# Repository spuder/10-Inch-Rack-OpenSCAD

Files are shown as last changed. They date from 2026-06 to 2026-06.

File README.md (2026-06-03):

# 10 Inch Rack Generator

OpenSCAD file to generate a 10 inch rack for 3d printing

[https://makerworld.com/models/1765102](https://makerworld.com/en/models/1765102-10-inch-mini-rack-generator)

10 Inch Mini-Rack v4

## My Presets

My personal model configurations are saved as Customizer presets in
[`10InchRackGenerator.json`](10InchRackGenerator.json). OpenSCAD auto-loads this
file (it shares the `.scad` basename), so each saved model appears in the
Customizer's preset dropdown — pick one, Render (f6), then export the STL.

To build a preset from the command line:

```bash
openscad -p 10InchRackGenerator.json -P "Xyber Hydra" -o out.stl 10InchRackGenerator.scad
```

Every saved preset is also covered by the test suite (see the
`customizer presets render` case below), so presets added via the Customizer get
rendered automatically with no test edits.

## Testing

### Manual Testing
1. Open OpenScad
2. Modify variables
3. Click 'Render' button (f6)

### CLI Testing
1. `openscad -o foobar.stl 10InchRackGenerator.scad`

### Automated Tests

Requires [bats-core](https://github.com/bats-core/bats-core), `openscad`, and
`jq` (used to read presets) on your `PATH`.

```bash
# Fast preview tests — renders PNG images, ~1s per case
make test

# Full geometry validation — renders STL files via CGAL, ~35s per case
make test-stl

# Run a single test by name
make test TEST=missing_air_holes

# Run a single test with stl
RENDER_STL=1 make test TEST=missing_air_holes

# Render every model saved in 10InchRackGenerator.json
make test TEST="customizer presets render"
```

The `customizer presets render` case reads
[`10InchRackGenerator.json`](10InchRackGenerator.json) at runtime, so any model
you save from the GUI Customizer is tested automatically — no test edits needed.

Output files land in `tests/renders/`. Each test case produces up to five PNG previews:

```
tests/renders/
  default_corner.png
  default_front.png
  default_side.png
  default_top.png
  default_bottom.png
  default.stl          ← only present after make test-stl
```

To run a specific named case and also get its STL alongside the PNGs:

```bash
make test TEST=dell_optiplex_7020
# → tests/renders/dell_optiplex_7020_{corner,front,side,top,bottom}.png
# → tests/renders/dell_optiplex_7020.stl
```

## Keystones

An openscad file to generate keystones is avilable [on makerworld](https://makerworld.com/en/models/2882057-keystone-jack#profileId-3219015)
A stl is available at ./keystone.stl and ./keystone.3mf

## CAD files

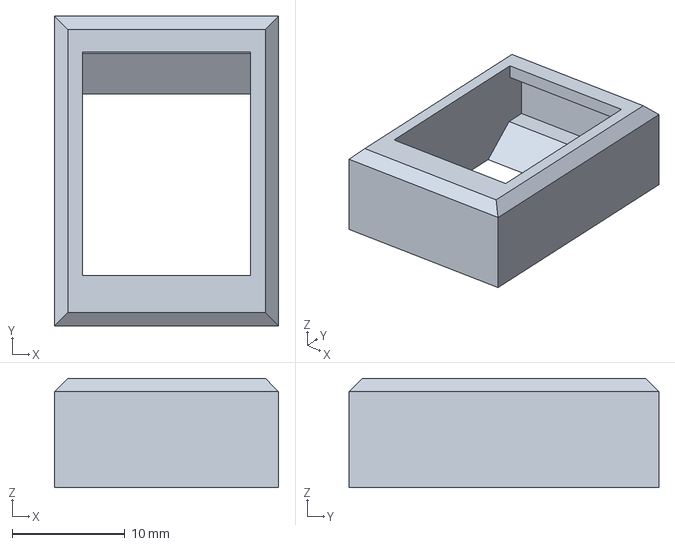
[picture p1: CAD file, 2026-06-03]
keystone.3mf
19.9 x 27.5 x 9.70 mm

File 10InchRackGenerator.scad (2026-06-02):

rack_width = 254.0; // [ 254.0:10 inch, 152.4:6 inch]
// Height of the rack in U units, can be a fraction for partial U (e.g. 1.5 for 1U plus half of the next U)
rack_height = 1.0; // [0.5:0.5:5]


component_width = 110.0;
component_depth = 122.0;
component_height = 28.30;

// ========================================
/* [Keystones] */
// Add keystone jacks to the front panel
keystones = false; // [true: Place keystone jacks, false: Remove keystone jacks]

// ========================================
/* [Holes] */
// Adds small cutout a USB or Power cable could be routed through to the front
front_wire_holes = false; // [true:Show front wire holes, false:Hide front wire holes]
// Diameter of wire to route through front_wire_holes.
wire_diameter = 7; // Diameter of power wire holes
// Adds hexagon air cutouts to reduce material and improve cooling.
air_holes = true; // [true:Show air holes, false:Hide air holes]

// ========================================
/* [Advanced] */
// Used when rack_height is a fraction, cuts a half oval for screws, otherwise will cover up the hole
half_height_holes = true; // [true:Show partial holes at edges, false:Hide partial holes]
// Thickness of the shell that wraps around the part.
case_thickness = 6; // Thickness of case walls
// Thickness of the front panel (the flat face plate).
front_plate_thickness = 3.0;
// Make the front plate solid (no hole), useful to hide a part not needing to be accessed from the exterior.
front_plate_hole = true; // [true:Show front plate hole, false:Solid front plate]
// Prevent part from sliding out the front by adding a small 0.6mm lip around the front plate hole.
front_lip = true; // [true:Show front lip, false:Hide front lip]
// Default gap between part and print walls
tolerance = 0.42;

// ========================================
/* [Hidden] */
height = 44.45 * rack_height;


// The main module containing all internal variables
module switch_mount(switch_width, switch_height, switch_depth) {
    //6 inch racks (mounts=152.4mm; rails=15.875mm; usable space=120.65mm)
    //10 inch racks (mounts=254.0mm; rails=15.875mm; usable space=221.5mm)
    chassis_width = min(switch_width + (2 * case_thickness), (rack_width == 152.4) ? 120.65 : 221.5);
    corner_radius = 4.0;
    chassis_edge_radius = 2.0;
    tolerance = 0.42;

    zip_tie_hole_count = 8;
    zip_tie_hole_width = 1.5;
    zip_tie_hole_length = 5;
    zip_tie_indent_depth = 2;
    zip_tie_cutout_depth = 7;

    // When the front is solid the switch slides in from the back, so everything
    // shifts rearward by front_plate_thickness to keep zip ties at the switch's back face.
    solid_z_offset = front_plate_hole ? 0 : front_plate_thickness;
    chassis_depth_main = switch_depth + zip_tie_cutout_depth + solid_z_offset;
    chassis_depth_indented = chassis_depth_main - zip_tie_indent_depth;

    hole_total_width = zip_tie_hole_count * zip_tie_hole_width;
    space_between_holes = (rack_width - hole_total_width) / (zip_tie_hole_count + 1);

    $fn = 64;

    // Calculated dimensions
    cutout_w = switch_width + (2 * tolerance);
    cutout_h = switch_height + (2 * tolerance);
    cutout_x = (rack_width - cutout_w) / 2;
    cutout_y = (height - cutout_h) / 2;

    // Keystone placement — jack X span (width) goes horizontal, jack Z span (height) goes vertical
    keystone_outer_width  = 19.9; // jack_width + wall = (front_hole_width + wall) + wall
    keystone_outer_height = 27.5; // jack_height + wall
    // Left edge of left keystone pinned to 210/2 from centreline → 210mm outer-to-outer for the mirrored pair
    keystone_tx = rack_width/2 - 105;
    keystone_ty = (height - keystone_outer_height) / 2;

    // Helper modules
    module capsule_slot_2d(L, H) {
        hull() {
            translate([-L/2 + H/2, 0]) circle(r=H/2);
            translate([L/2 - H/2, 0]) circle(r=H/2);
        }
    }
    
    module rounded_rect_2d(w, h, r) {
        hull() {
            translate([r, r]) circle(r=r);
            translate([w-r, r]) circle(r=r);
            translate([w-r, h-r]) circle(r=r);
            translate([r, h-r]) circle(r=r);
        }
    }

    module rounded_chassis_profile(width, height, radius, depth) {
        hull() {
            translate([radius, radius, 0]) cylinder(h = depth, r = radius);
            translate([width - radius, radius, 0]) cylinder(h = depth, r = radius);
            translate([radius, height - radius, 0]) cylinder(h = depth, r = radius);
            translate([width - radius, height - radius, 0]) cylinder(h = depth, r = radius);
        }
    }
    
    // Create the main body as a separate module
    module main_body() {
        side_margin = (rack_width - chassis_width) / 2;
        chassis_height = min(switch_height + (2 * case_thickness), height);
        union() {
            // Front panel
            linear_extrude(height = front_plate_thickness) {
                rounded_rect_2d(rack_width, height, corner_radius);
            }
            // Chassis body
            translate([side_margin, (height - chassis_height) / 2, front_plate_thickness]) {
                rounded_chassis_profile(chassis_width, chassis_height, chassis_edge_radius, chassis_depth_main - front_plate_thickness);
            }
        }
    }
    
    // Create switch cutout with optional lip
    module switch_cutout() {
        if (front_plate_hole && front_lip) {
            lip_thickness = 1.2;
            lip_depth = 0.60;
            // Main cutout minus lip (centered)
            translate([
                (rack_width - (cutout_w - 2*lip_thickness)) / 2,
                (height - (cutout_h - 2*lip_thickness)) / 2,
                -tolerance
            ]) {
                cube([cutout_w - 2*lip_thickness, cutout_h - 2*lip_thickness, chassis_depth_main]);
            }
            // Switch cutout above the lip (centered)
            translate([
                (rack_width - cutout_w) / 2,
                (height - cutout_h) / 2,
                lip_depth
            ]) {
                cube([cutout_w, cutout_h, chassis_depth_main]);
            }
        } else {
            // Full cutout: starts at front face when front_plate_hole, or behind front panel when solid
            z_start = front_plate_hole ? -tolerance : front_plate_thickness;
            z_depth = front_plate_hole ? chassis_depth_main + 2*tolerance : chassis_depth_main - front_plate_thickness + tolerance;
            translate([
                (rack_width - cutout_w) / 2,
                (height - cutout_h) / 2,
                z_start
            ]) {
                cube([cutout_w, cutout_h, z_depth]);
            }
        }
    }
    
    // Create all rack holes
    module all_rack_holes() {
        // Rack standard: 3 holes per U, with specific positioning
        // Each U is 44.45mm, holes are at specific positions within each U
        hole_spacing_x = (rack_width == 152.4) ? 136.526 : 236.525; // 6 inch : 10 inch rack
        hole_left_x = (rack_width - hole_spacing_x) / 2;
        hole_right_x = (rack_width + hole_spacing_x) / 2;

        // 10 inch rack = 10x7mm oval
        // 6 inch rack = 3.25 x 6.5mm oval
        slot_len = (rack_width == 152.4) ? 6.5 : 10.0;
        slot_height = (rack_width == 152.4) ? 3.25 : 7.0;

        // Standard rack hole positions within each 1U (44.45mm) unit:
        // First hole: 6.35mm from top of U
        // Second hole: 22.225mm from top of U (middle)
        // Third hole: 38.1mm from top of U (6.35mm from bottom)
        u_hole_positions = [6.35, 22.225, 38.1]; // positions within each U
        
        // Calculate how many full and partial U units we need to consider
        max_u = ceil(rack_height); // Include partial U units
        
        for (side_x = [hole_left_x, hole_right_x]) {
            for (u = [0:max_u-1]) {
                for (hole_pos = u_hole_positions) {
                    // Calculate hole position from top of entire rack
                    hole_y = height - (u * 44.45 + hole_pos);
                    // Always show holes that are at least partially within the rack height
                    // Always show holes fully inside the rack
                    fully_inside = (hole_y >= slot_height/2 && hole_y <= height - slot_height/2);
                    // Show partial holes at edge only if half_height_holes is true
                    partially_inside = (hole_y + slot_height/2 > 0 && hole_y - slot_height/2 < height);
                    show_hole = fully_inside || (half_height_holes && partially_inside && !fully_inside);
                    if (show_hole) {
                        translate([side_x, hole_y, 0]) {
                            linear_extrude(height = chassis_depth_main) {
                                capsule_slot_2d(slot_len, slot_height);
                            }
                        }
                    }
                }
            }
        }
    }
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

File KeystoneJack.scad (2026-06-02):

cross_section_preview=true;
module keystone(
){
    e=0.01; // epsilon for coplanar face fixes, fixes bug where some faces leave a thin sliver of material
    wall=2.5;
    front_hole_width=14.9;
    front_hole_height=16.3;
    front_hole_z_offset=4.28;
    front_hole_lip=0;

    jack_width=front_hole_width+wall;
    jack_height=25;
    jack_depth=9.7;
    front_large_catch_depth=3;
    front_chamfer_angle=50; // degrees from horizontal (depth axis)

    back_hole_height=24.4;
    back_hole_z_offset=1.9;

    back_small_catch_length=2;
    back_small_catch_depth=1.4;

    back_large_catch_length=2.6;
    back_large_catch_depth=1.3;
    
    back_chamfer=1.2;

    // Flip entire part because I accidentially desinged it upside down
    translate([0, 0, jack_height + wall]) 
    mirror([0, 0, 1]) {
        union(){
            difference(){
                // Make solid cube
                cube([jack_width+wall,jack_depth,jack_height+wall]);
            // Cut out the front hole
            translate([(jack_width+wall-front_hole_width)/2,0,front_hole_z_offset])
                color("blue")
                cube([front_hole_width,jack_depth+wall,front_hole_height]);
            // Cut out the back hole. It should be extruded to front_large_catch_depth
            translate([(jack_width+wall-front_hole_width)/2,front_large_catch_depth,back_hole_z_offset])
                color("red")
                cube([front_hole_width,jack_depth+wall-front_large_catch_depth,back_hole_height]);

            // Cut out chamfer on front face of small catch
            color("green")
            translate([wall + front_hole_width, 0, 0])
                rotate([0, -90, 0])
                    linear_extrude(front_hole_width)
                        polygon([
                            [front_hole_z_offset + front_hole_height - e, front_hole_lip - e],          // A: shifted e below catch floor to avoid coplanar artifact
                            [front_hole_z_offset + front_hole_height + (front_large_catch_depth - front_hole_lip) * tan(front_chamfer_angle), front_large_catch_depth],  // B: angle-derived point
                            [front_hole_z_offset + front_hole_height - e, front_large_catch_depth]      // C: inner corner, same e shift as A
                        ]);

            // Cut out chamefer on front face of large catch
            // color("orange")
            // translate([wall + front_hole_width, 0, 0])
            //     rotate([0, -90, 0])
            //         linear_extrude(front_hole_width)
            //             polygon([
            //                 [front_hole_z_offset+e, front_hole_lip],  // A: front face, bottom of front hole
            //                 [back_hole_z_offset,  front_large_catch_depth],     // B: inner ledge, bottom of back hole
            //                 [front_hole_z_offset, front_large_catch_depth]      // C: inner ledge, same Z as A
            //             ]);

            // Front directional triangle emboss (cut into face)
            color("yellow")
                translate([(jack_width+wall)/2, 0.4, (front_hole_z_offset + front_hole_height + jack_height + wall) / 2])
                    rotate([90, 0, 0])
                        linear_extrude(height = 0.4+e)
                            polygon([
                                [0, -2],
                                [-2, 2],
                                [2, 2]
                            ]);

            // Chamfer back bottom edge (along X)
            translate([jack_width+wall+e, 0, -e])
                rotate([0, -90, 0])
                    linear_extrude(jack_width+wall+2*e)
                        polygon([[-e, jack_depth+e], [back_chamfer, jack_depth+e], [-e, jack_depth-back_chamfer]]);

            // Chamfer back top edge (along X)
            translate([jack_width+wall+e, 0, -e])
                rotate([0, -90, 0])
                    linear_extrude(jack_width+wall+2*e)
                        polygon([[jack_height+wall+2*e, jack_depth+e], [jack_height+wall+2*e-back_chamfer, jack_depth+e], [jack_height+wall+2*e, jack_depth-back_chamfer]]);

            // Chamfer back left edge (along Z)
            translate([0, 0, -e])
                linear_extrude(jack_height+wall+2*e)
                    polygon([[-e, jack_depth+e], [back_chamfer, jack_depth+e], [-e, jack_depth-back_chamfer]]);

            // Chamfer back right edge (along Z)
            translate([0, 0, -e])
                linear_extrude(jack_height+wall+2*e)
                    polygon([[jack_width+wall+e, jack_depth+e], [jack_width+wall+e-back_chamfer, jack_depth+e], [jack_width+wall+e, jack_depth-back_chamfer]]);

            } // end difference

            // Small back catch (added geometry)
            color("purple")
                translate([wall + front_hole_width, 0, 0])
                    rotate([0, -90, 0])
                        linear_extrude(front_hole_width)
                            polygon([
                                [back_hole_z_offset + back_hole_height - back_small_catch_length, jack_depth - back_small_catch_depth],  // A
                                [back_hole_z_offset + back_hole_height,                           jack_depth - back_small_catch_depth],  // B
                                [back_hole_z_offset + back_hole_height,                           jack_depth],                           // C
                                [back_hole_z_offset + back_hole_height - back_small_catch_length, jack_depth]                            // D
                            ]);

            // Large back catch (added geometry)
            color("cyan")
                translate([wall + front_hole_width, 0, 0])
                    rotate([0, -90, 0])
                        linear_extrude(front_hole_width)
                            polygon([
                                [back_hole_z_offset,                           jack_depth - back_large_catch_depth],  // A
                                [back_hole_z_offset + back_large_catch_length, jack_depth - back_large_catch_depth],  // B
                                [back_hole_z_offset + back_large_catch_length, jack_depth],                           // C
                                [back_hole_z_offset,                           jack_depth]                            // D
                            ]);

        } // end union
    }
}


if ($preview && cross_section_preview) {
    intersection() {
        keystone();
        cube([10, 35, 50]);
    }
} else if ($preview) {
    keystone();
} else {
    rotate([90, 0, 0])
        keystone();
}

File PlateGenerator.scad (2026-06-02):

// Rack Width 10 inch or 6 inch
rack_width = 254.0; // [ 254.0:10 inch, 152.4:6 inch]
// Height (measured in U)
rack_height = 1.0; // [0.5:0.5:5]
// Thickness of the front plate
front_thickness = 3.0;
// Radius for rounded corners on the front plate
corner_radius = 4.0;
half_height_holes = true; // [true:Show partial holes at edges, false:Hide partial holes]
//Adds additional strength
ribs = true; // [true:Show structural ribs, false:Hide structural ribs]
//Optional keystone jacks
keystones = 0; // [0:1:10]

/* [Hidden] */
height = 44.45 * rack_height;

tolerance = 0.42;

// Structural rib parameters
rib_thickness = 2.0;
rib_depth = 3.0;
rib_spacing = 15.0; // Distance between ribs
chamfer_size = 0.5; // Size of chamfer on rib edges

module keystone() {
    e=0.01;
    wall=2.5;
    front_hole_width=14.9;
    front_hole_height=16.3;
    front_hole_z_offset=4.28;
    front_hole_lip=0;

    jack_width=front_hole_width+wall;
    jack_height=25;
    jack_depth=9.7;
    front_large_catch_depth=3;
    front_chamfer_angle=50;

    back_hole_height=24.4;
    back_hole_z_offset=1.9;

    back_small_catch_length=2;
    back_small_catch_depth=1.4;

    back_large_catch_length=2.6;
    back_large_catch_depth=1.3;

    back_chamfer=1.2;

    translate([0, 0, jack_height + wall])
    mirror([0, 0, 1]) {
        union(){
            difference(){
                cube([jack_width+wall,jack_depth,jack_height+wall]);
                translate([(jack_width+wall-front_hole_width)/2,0,front_hole_z_offset])
                    cube([front_hole_width,jack_depth+wall,front_hole_height]);
                translate([(jack_width+wall-front_hole_width)/2,front_large_catch_depth,back_hole_z_offset])
                    cube([front_hole_width,jack_depth+wall-front_large_catch_depth,back_hole_height]);
                translate([wall + front_hole_width, 0, 0])
                    rotate([0, -90, 0])
                        linear_extrude(front_hole_width)
                            polygon([
                                [front_hole_z_offset + front_hole_height - e, front_hole_lip - e],
                                [front_hole_z_offset + front_hole_height + (front_large_catch_depth - front_hole_lip) * tan(front_chamfer_angle), front_large_catch_depth],
                                [front_hole_z_offset + front_hole_height - e, front_large_catch_depth]
                            ]);
                translate([jack_width+wall+e, 0, -e])
                    rotate([0, -90, 0])
                        linear_extrude(jack_width+wall+2*e)
                            polygon([[-e, jack_depth+e], [back_chamfer, jack_depth+e], [-e, jack_depth-back_chamfer]]);
                translate([jack_width+wall+e, 0, -e])
                    rotate([0, -90, 0])
                        linear_extrude(jack_width+wall+2*e)
                            polygon([[jack_height+wall+2*e, jack_depth+e], [jack_height+wall+2*e-back_chamfer, jack_depth+e], [jack_height+wall+2*e, jack_depth-back_chamfer]]);
                translate([0, 0, -e])
                    linear_extrude(jack_height+wall+2*e)
                        polygon([[-e, jack_depth+e], [back_chamfer, jack_depth+e], [-e, jack_depth-back_chamfer]]);
                translate([0, 0, -e])
                    linear_extrude(jack_height+wall+2*e)
                        polygon([[jack_width+wall+e, jack_depth+e], [jack_width+wall+e-back_chamfer, jack_depth+e], [jack_width+wall+e, jack_depth-back_chamfer]]);
                translate([(jack_width+wall)/2, 0.4, (front_hole_z_offset + front_hole_height + jack_height + wall) / 2])
                    rotate([90, 0, 0])
                        linear_extrude(height = 0.4+e)
                            polygon([[0, -2], [-2, 2], [2, 2]]);
            }
            translate([wall + front_hole_width, 0, 0])
                rotate([0, -90, 0])
                    linear_extrude(front_hole_width)
                        polygon([
                            [back_hole_z_offset + back_hole_height - back_small_catch_length, jack_depth - back_small_catch_depth],
                            [back_hole_z_offset + back_hole_height,                           jack_depth - back_small_catch_depth],
                            [back_hole_z_offset + back_hole_height,                           jack_depth],
                            [back_hole_z_offset + back_hole_height - back_small_catch_length, jack_depth]
                        ]);
            translate([wall + front_hole_width, 0, 0])
                rotate([0, -90, 0])
                    linear_extrude(front_hole_width)
                        polygon([
                            [back_hole_z_offset,                           jack_depth - back_large_catch_depth],
                            [back_hole_z_offset + back_large_catch_length, jack_depth - back_large_catch_depth],
                            [back_hole_z_offset + back_large_catch_length, jack_depth],
                            [back_hole_z_offset,                           jack_depth]
                        ]);
        }
    }
}

// The main module for the plate generator
module plate_generator() {
    $fn = 64;

    // Helper module for capsule-shaped slots (oval holes)
    module capsule_slot_2d(L, H) {
        hull() {
            translate([-L/2 + H/2, 0]) circle(r=H/2);
            translate([L/2 - H/2, 0]) circle(r=H/2);
        }
    }
    
    // Helper module for rounded rectangle
    module rounded_rect_2d(w, h, r) {
        hull() {
            translate([r, r]) circle(r=r);
            translate([w-r, r]) circle(r=r);
            translate([w-r, h-r]) circle(r=r);
            translate([r, h-r]) circle(r=r);
        }
    }
    
    // Helper module for simple chamfered rib (much faster)
    module chamfered_rib(width, thickness, depth, chamfer) {
        difference() {
            // Main rib body
            cube([width, thickness, depth]);
            
            // Large 45° chamfer to remove entire corner
            // Left end chamfer - dynamic positioning based on depth
            translate([depth - depth * 2, -tolerance, depth])
                rotate([0, 45, 0])
                    cube([depth * 1.5, thickness + 2*tolerance, depth * 1.5]);
            // Right end chamfer - dynamic positioning based on depth
            translate([width - depth + depth, -tolerance, 0])
                rotate([0, -45, 0])
                    cube([depth * 1.5, thickness + 2*tolerance, depth * 1.5]);
        }
    }
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

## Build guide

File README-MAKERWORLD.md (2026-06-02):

## MiniRack Generator

Do you have a 10 inch mini rack, but don't want to design the shelves yourself? 
Easily generate your own 10 inch rack shelves, no CAD required. 

### Customization

Click the Green "Customize" and enter the dimensions of your device.



A 0.42 mm tolerance is built in, which works well for most models. 

#### Available Parameters

Set `switch_width`, `switch_depth`, and `switch_height` to the width, depth, and height of the device you want to mount.

- **rack_width** (254.0) — 254 = 10 inch rack, 152.4 = 6 inch rack
- **rack_height** (1.0) — Height in U units (0.5–5U, each U = 44.45 mm)
- **switch_width** (135.0) — Width of the device, left to right (mm)
- **switch_depth** (135.0) — Depth of the device, front to back (mm)
- **switch_height** (28.3) — Height of the device (mm)
- **front_wire_holes** (false) — Adds small holes to route a USB or power cable through the front
- **wire_diameter** (7) — Diameter of front wire holes (mm)
- **air_holes** (true) — Hexagon cutouts on sides and back to reduce material and improve cooling
- **half_height_holes** (true) — Show partial rack mounting holes when rack_height is a fraction
- **case_thickness** (6) — Thickness of the shell walls (mm)
- **front_plate_thickness** (3.0) — Thickness of the front face plate (mm)
- **front_plate_hole** (true) — When false, front plate is solid — useful for devices that don't need front access
- **front_lip** (true) — Adds a small lip around the front opening to prevent the device from sliding out
- **tolerance** (0.42) — Gap added to each side between device and shell walls (mm)

#### Known Dimensions

##### Networking

- Firewalla Gold: `120 x 120 x 30 mm`*
- Firewalla Purple (Ethernet): `130 x 110 x 34 mm`*
- Firewalla Purple SE: `90 x 60 x 30 mm`*
- UniFi Security Gateway: `135 x 135 x 28.3 mm`*
- UniFi Cloud Key G2+: `131.2 x 27.1 x 134.2 mm`*
- UniFi Flex Mini: `107 x 70 x 21 mm`*
- UniFi Flex Mini 2.5G: `117.1 x 90 x 21.2 mm`*
- UniFi Flex 2.5: `212.9 x 76 x 33.5 mm`*
- UniFi Lite 8 POE: `99.6 x 163.7 x 31.7 mm`*
- UniFi Lite 16 POE: `192 x 185 x 44 mm`*
- UniFi Express: `98 x 98 x 30 mm`*
- UniFi Cloud Gateway Ultra/Max: `141.8 x 127.6 x 30 mm`*

##### Compute

- IBM M70q Gen 5: `179 x 182.9 x 36.5 mm`*
- IBM M70q Gen 4: `179 x 183 x 34.5 mm`*
- IBM M90q Gen 5: `179 x 182.9 x 36.5 mm`*
- Dell OptiPlex 7020: `182 x 178 x 36 mm`*
- HP Elite Mini 800: `177.5 x 175.2 x 34.3 mm`*
- M4 Mac Mini: `127 x 127 x 50 mm`*
- BeeLink ME Mini: `99 x 99 x 99 mm`*
- Xyber Hydra: `140 x 98.5 x 34.5 mm`*

##### Storage

- Synology DS223j: `165 x 100 x 225.5 mm`*
- Synology DS223: `165 x 108 x 232.7 mm`*
- Synology DS124: `166 x 71 x 224 mm`*

*\* Dimensions are Width × Depth × Height*

#### Related Projects

- [10 Inch parametric shelf generator](https://makerworld.com/en/models/1421393-parametric-10-inch-rack-shelf)
- [Alternative 10 inch rack generator with cage](https://github.com/WebMaka/ParametricRackCageGenerator)
- [OpenRack - A 19Inch modular system](https://makerworld.com/en/models/1032069-openrack-1u-a-modular-server-rack-system)

Source Code is [available on github](https://github.com/spuder/10-Inch-Rack-OpenSCAD)

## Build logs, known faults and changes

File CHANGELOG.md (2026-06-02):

CHANGELOG.md
## v1.11.1
- Add keystone jacks to PlateGenerator.scad

## v1.11.0
- Add optional keystone jack mounts (`keystones` parameter) — two mounts placed symmetrically at the maximum 210mm usable width limit, one per rack ear
- Overhauled KeystoneJack.scad to make easier to modify. Will be released as own makerworld file
- Add .json files to store presets
- Overhaul tests
- Remove `print_orientation` and replaced with builtin $preview variable

## v1.10.0
- Rename `switch_width/depth/height` parameters to `component_width/depth/height`
- Fix chassis overflowing rack panel when `component_height + 2*case_thickness` exceeds the rack unit height

## v1.9.0
- Adds testing
- Fix missing holes when `component_height` is within 6mm of `rack_height` [github #9](https://github.com/spuder/10-Inch-Rack-OpenSCAD/issues/9)

## v1.8.0
- Add `front_plate_hole` parameter to optionally keep the front panel solid
- Add `front_plate_thickness` parameter to control front panel depth
- Improved tabbed grouping of variables in UI

## v1.7.1
- Fix regression that hid vars

## v1.7.0
- Makes front lip configurable
- General improvments in parameter grouping

## v1.6.0
- Adds variable for wire_diameter

## v1.5.0
- Add variable to change case thickness (defaults to 6)

## v1.4.0
- Initial release of plate generator

## v1.3.1
- Change default values to USG dimensions
- Make tolerance a user changable parameter

## v1.3.0
- Reduce material usage above/below switch (now walls are 6mm)

## v1.2.1
- Allow air holes on smaller parts

## v1.2.0
- Improve hexagon spacing
- Support half height racks

## v1.1.1
- Increase front ear radius from 2 to 4mm

## v1.1.0
- Change squares to hexagons because hexagons are the bestagons
- Add side air holes
- Simplify logic for air holes

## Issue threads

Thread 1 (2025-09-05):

Skeletonize for better airflow

spuder, 2025-09-05:
Improve the hole design for better airflow.

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

## What

Create a skeletonized version like this skull

https://www.voronator.com/

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

## How

OpenSCAD on makerworld has [these libraries](https://www.reddit.com/r/BambuLab/comments/1jl6ypa/how_to_create_customizable_models_on_maker_world/) included.

The most promising are:
https://github.com/BelfrySCAD/BOSL2/wiki/TOC
https://github.com/UBaer21/UB.scad?tab=readme-ov-file#ubscad

While this library isn't included in openscad on makerworld, it might be possible to request bambu to add it.

https://www.printables.com/model/831732-fast-voronoi-method-for-openscad

Note that it may be prohibitively slow

https://www.reddit.com/r/openscad/comments/s8f5zm/comment/htfx6xi/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

This library also isn't available nativly but it has a voronoi module

https://github.com/JustinSDK/dotSCAD

spuder, 2025-09-05:
Switched to hexagons

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

Closed 2025-09-05.

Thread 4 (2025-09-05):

Increase switch width

spuder, 2025-09-05:
The walls are hard coded to 6mm which limits the width of switch that can be used

> 209.5mm wide switch (or 108.65mm if using 6").
> But I think it would be safe to stretch it to 217.5mm. It would give 2mm of wall which should still be fine.

https://www.reddit.com/r/minilab/comments/1n8p2a9/comment/nckaq2b/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

Shrink the wall thickness to allow for wider switches

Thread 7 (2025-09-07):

Support multiple devices in one mount

MoshiBin, 2025-09-07:
Some devices are smaller than half a 10" rack, allowing for multiple devices in one mount.

In my case, I want to mount both a MoCA adapter and an ONT. These both fit within 1U with ample spacing.

To visualize this, I hacked the script to add an "offset" variable, rendered each device independently with a different offset, then overlaid both models in the slicer. This won't work since the front panel of each exported model interferes with the hole of the other, so it's just to visualize what I want to achieve:

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

If this can be extended enough, this can pave the way for "blade" mounts, for example SBCs like the Raspberry Pi mounted vertically in 2U can likely fit ~6 units.

I'm not comfortable enough with OpenSCAD to contribute this myself, and the LLMs I tried did an awful job trying to add this feature.

spuder, 2025-09-10:
Thanks for the detailed explanation. I see that this could be valuable. I'll look at a way to make this flexible while still intuitive for users.

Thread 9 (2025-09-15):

Holes not created if part too thick

spuder, 2025-09-15:
Design currently Allow users to make units that are slightly larger than 1 U
However it does not have air holes if they do.

Consider fixing this edge case.

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

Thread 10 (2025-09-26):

Small overhang for Dell OptiPlex 7020 1U rack mount

SilverHazeLazers, 2025-09-26:
Firstly a big thanks for this project - it's such a lifesaver as I am building out my rack

I am trying to print a rack mount of a Dell OptiPlex 7020 which has a height of 36mm

Unfortunately, there is a slight overhand on both the top and bottom of the 1U rack mount. I'm not actually sure if this is solvable with a smaller wall width or alike but thought I would share here in case you have any suggestions

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

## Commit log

2025-09-04 Add zip tie indents
    [10InchRackGenerator.scad]
2025-09-04 Best practices
    [10InchRackGenerator.scad]
2025-09-04 fix lip, make 10 inch a parameter
    [10InchRackGenerator.scad]
2025-09-04 support more than 1 U
    [10InchRackGenerator.scad]
2025-09-04 Add front wire holes
    [10InchRackGenerator.scad]
2025-09-04 Add airholes
    [10InchRackGenerator.scad]
2025-09-04 improve air holes
    [10InchRackGenerator.scad]
2025-09-04 cleanup comments
    [10InchRackGenerator.scad]
2025-09-04 Increase tolerances
    [10InchRackGenerator.scad]
2025-09-04 center for makerworld
    [10InchRackGenerator.scad]
2025-09-04 turn off 10 inch drop down
    [10InchRackGenerator.scad]
2025-09-04 Increase hole size of ears, Increase wire hole size
    [10InchRackGenerator.scad]
2025-09-04 Increase lip thickness
    [10InchRackGenerator.scad]
2025-09-04 Support 6 inch rack
    [10InchRackGenerator.scad]
2025-09-04 rename variables
    [10InchRackGenerator.scad]
2025-09-05 Add print orientation parameter
    [10InchRackGenerator.scad]
2025-09-05 Improve hexagon holes
    [10InchRackGenerator.scad]
2025-09-05 Increase corner radius to 4
    [10InchRackGenerator.scad]
2025-09-05 Improve hexagon spacing
    [10InchRackGenerator.scad]
2025-09-05 Support 1/2 height U
    [10InchRackGenerator.scad]
2025-09-05 Support half height holes
    [10InchRackGenerator.scad]
2025-09-06 Add keystone jack
    [KeystoneJack.scad]
2025-09-06 Allow air holes on smaller parts
    [10InchRackGenerator.scad]
2025-09-06 Working keystone jack
    [10InchRackGenerator.scad]
2025-09-06 fix keystone jacks
    [KeystoneJack.scad]
2025-09-10 Reduce material usage vertically
    [10InchRackGenerator.scad]
2025-09-11 Add variable
    [10InchRackGenerator.scad]
2025-09-14 Change default dimensions
    [10InchRackGenerator.scad]
2025-09-19 Add plate generator
    [PlateGenerator.scad]
2026-03-11 Add v1.5.0 entry for case thickness variable
2026-05-27 Make front lip optional
    [10InchRackGenerator.scad]
2026-05-27 Group front lip parameters
    [10InchRackGenerator.scad]
2026-05-27 Revert "Group front lip parameters"
    This reverts commit 892b0ce45764f4cfaa129c6f3eb210115b0a9c9d.
    [10InchRackGenerator.scad]
2026-05-27 Add front_plate_hole parameter to allow for non through hole parts
    [10InchRackGenerator.scad]
2026-05-27 Make front_plate_thickness a user definable parameter
    [10InchRackGenerator.scad]
2026-05-28 Add tests
    [10InchRackGenerator.scad]
2026-05-28 fix missing holes
    [10InchRackGenerator.scad]
2026-05-29 Add keystones
    [10InchRackGenerator.scad]
2026-05-29 disable keystones by default
    [10InchRackGenerator.scad]
2026-05-29 Add chamfers to keyston
    [10InchRackGenerator.scad, KeystoneJack.scad]
2026-05-29 Cleanup hard coded variables in keystone
    [10InchRackGenerator.scad, KeystoneJack.scad]
2026-05-29 Revert print orentation slipup
    [10InchRackGenerator.scad]
2026-06-01 Overhault keystone jack
    [KeystoneJack.scad]
2026-06-02 fix small artifact
    [KeystoneJack.scad]
2026-06-02 flip entire part
    [KeystoneJack.scad]
2026-06-02 keystone overhaul
    [10InchRackGenerator.scad, KeystoneJack.scad, PlateGenerator.scad]
2026-06-02 add keystone jacks to front plate
    [PlateGenerator.scad]
2026-06-02 Add plates
2026-06-03 Add more parts
    [keystone.3mf]
2026-06-04 Add sodola Switch
